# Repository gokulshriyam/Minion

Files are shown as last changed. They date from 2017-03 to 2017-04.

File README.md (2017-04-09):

1. PRODUCT :

Minion is for all electricity consumers across the world to help reduce their power costs at an affordable price point using "user friendly" products & analysis.

As there are many IOT Smart Energy Devices in the market that ensures energy efficiency and cost saving but it makes monthly electric bills doubling or tripling every month, with no increase in energy usage. 

We had carefully read solutions of all existing smart meters across the world and identified the perfect use case which ensures 100% energy efficiency and cost saving to the electricity consumers

Minion is a single device (size: 39x49 Millimeter - World's smallest pocket energy auditor) with Wi-Fi,LORA,3G/4G Connectivity which will fit inside the breaker panel (next to utility meter like addon) with single sensor clamp connection after the utility meter.

This Minion will perform appliance/device/tool/equipment wise real-time energy analytics. It will also perform Predictive analytics & maintenance of assets (Hospital, Industrial, Manufacturing/factories, Hospitality, Retail) which rescues the high cost assets from breakdown and also lowers the insurance costs. It schedules maintenance which will ensure and extend the life-time of assets beyond insurance time.

Our Minion is also Solar friendly/compatible. It has the ability to measure generation and consumption readings (acts as net meter) and performs real time & predictive analytics. 

All the analytics are done on the cloud and enable users to experience the results through our SaaS - Windows application, Android & IoS Apps.

Our Minion provides three steps for ensuring 100% energy efficiency and cost saving

1. Realtime analytics - Let's user know what is he/she spending for at appliance level at any sectors (Residential, Hospitality, Hospitals, Industrial and more)

2. Predictive analytics - Reduces surprises in energy bills and User's can easily predict the energy usage and bills and schedule accordingly. This would be very useful for sectors running high cost assets which will prevent from breakdown and increase the efficiency of the assets.

3. Operating System (OS) - The predictive analytics with data and sensors leads to Operating system which ensures 100% of efficiency & cost saving. Without the help of human interfering, Our OS will perform automation inside buildings.

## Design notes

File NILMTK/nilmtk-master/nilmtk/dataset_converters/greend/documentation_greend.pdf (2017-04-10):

# GREEND Parser and Metadata for NILMTK

Johannes Holzl ¨
The Dark Side of Force
johannes.hoelzl@gmail.com

Abstract—GREEND[MEE⁺14] is a dataset which has been developed and collected in Carinthia and parts of Italy. It contains eight buildings and a couple of months of power measurement.
NILM-Metadata[KK14] is project which was designed for being used with NILM-TK[BKP⁺14], the free and open source Non-Intrusive Load Monitoring Toolkit.
I. INTRODUCTION

The GREEND parser has been developed in the thought of converting this particular dataset into a general, easy-to-use and most of all, a comparable structure. As many other parsers for NILM-TK, it converts the dataset into a standardized format which is also known as NILMTK-DF. Using a hdf5 file instead of a punch of csv or similar files has advantages such as the increase of performance when importing the dataset to the program, overall size on disk, which is much smaller and the circumstance that is just a single file containing all data and metadata makes it much more comfortable to use than the previously described scenario.

II. USING THE PARSER

The GREEND parser is stored in a file which is called convert_greend.py as the function convert_greend. It takes to strings as parameters which both describe paths. The first parameter gives in the path to the directory in which the GREEND dataset is stored. The second one is the location in which the outputted hdf5 file should be saved to.
When using the parser, keep in mind that GREEND is using up quite some disk space because of its sample rate of one second and its long recording period.
A. Example on using the GREEND parser

This Example shows the Usage of the GREEND parser which converts the data stored at greend/path to a hdf5 file at path/to/greend.h5.

convert_greend(’greend/path’, ’path/to/greend.h5’)

Fig. 1. Example of Converting GREEND

B. Using the Dataset

The hdf5 file could now be used with NILM-TK as expected. With NILM-TK v0.2 there is a class called HDFDataStore which could be, and is usually used to import hdf5 files. To finally load the dataset in form in which it could be used, it is indispensable to create a DataSet object and call its function load() with the HDFDataStore as a parameter.

C. Technical Background

The GREEND converter is not much different than the REDD one. They differ in the fact, that every meter contained in REDD has its own file with data in it, while in GREEND, every day is stored in a separate file with multiple columns for the appliances.

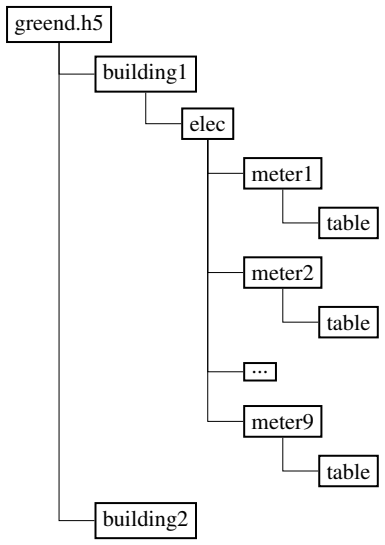
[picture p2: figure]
greend.h5; building1; elec; meter1; table; meter2; meter9; building2

Fig. 2. Structure of the Dataset

REFERENCES

[BKP⁺14] Nipun Batra, Jack Kelly, Oliver Parson, Haimonti Dutta, William Knottenbelt, Alex Rogers, Amarjeet Singh, and Mani Srivastava. Nilmtk: An open source toolkit for non-intrusive load monitoring. In Proceedings of the 5th International Conference on Future Energy Systems, e-Energy ’14, pages 265–276. ACM, 2014.
[KK14] | Jack Kelly and William Knottenbelt. | Metadata for Energy
Disaggregation. In The 2nd IEEE International Workshop on
Consumer Devices and Systems (CDS 2014), Vaster ¨ | as, Sweden, ˚
| July 2014.
[MEE⁺14] Andrea Monacchi, Dominik Egarter, Wilfried Elmenreich, Salvatore DAlessandro, and Andrea M. Tonello. GREEND: an energy consumption dataset of households in Italy and Austria. In Proceedings of the IEEE International Conference on Smart Grid Communications (SmartGridComm’14), November 2014.

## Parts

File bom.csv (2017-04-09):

Location | MPN | Quantity
C12, C11 | 06031A270JAT2A | 2
C14 | UWD1H221MCL1GS | 1
C15 | EEE-0GA101SR | 1
C5, C4, C13, C10 | 06035C333JAT2A | 4
C7, C3 | 0603YD334KAT2A | 2
C8, C1 | TAJA106K016RNJ | 2
C9, C6, C2, C17, C16 | GRM188R71H104KA93D | 5
D1 | MBRA140T3G | 1
D2 | B130LAW-7-F | 1
J1 | ST-PJ-312 | 1
J4 | 6.94E+11 | 1
PWR | LTST-C190KGKT | 1
Q1 | ABLS3-8.192MHZ-D4Y-T | 1
R10 | CR0603-FX-1003ELF | 1
R12 | 1-1614884-9 | 1
R5, R1 | ERJ-3EKF1000V | 2
R8, R7 | CRCW06032R40FKEAHP | 2
R9, R6, R3, R2, R13 | CRCW06031K00FKEA | 5
U1 | ATM90E26-YU-R | 1
U2 | TLV1117-50CDCYR | 1
J3, J2 | 110990037 | 2
R11 | RC0603JR-070RL | 1

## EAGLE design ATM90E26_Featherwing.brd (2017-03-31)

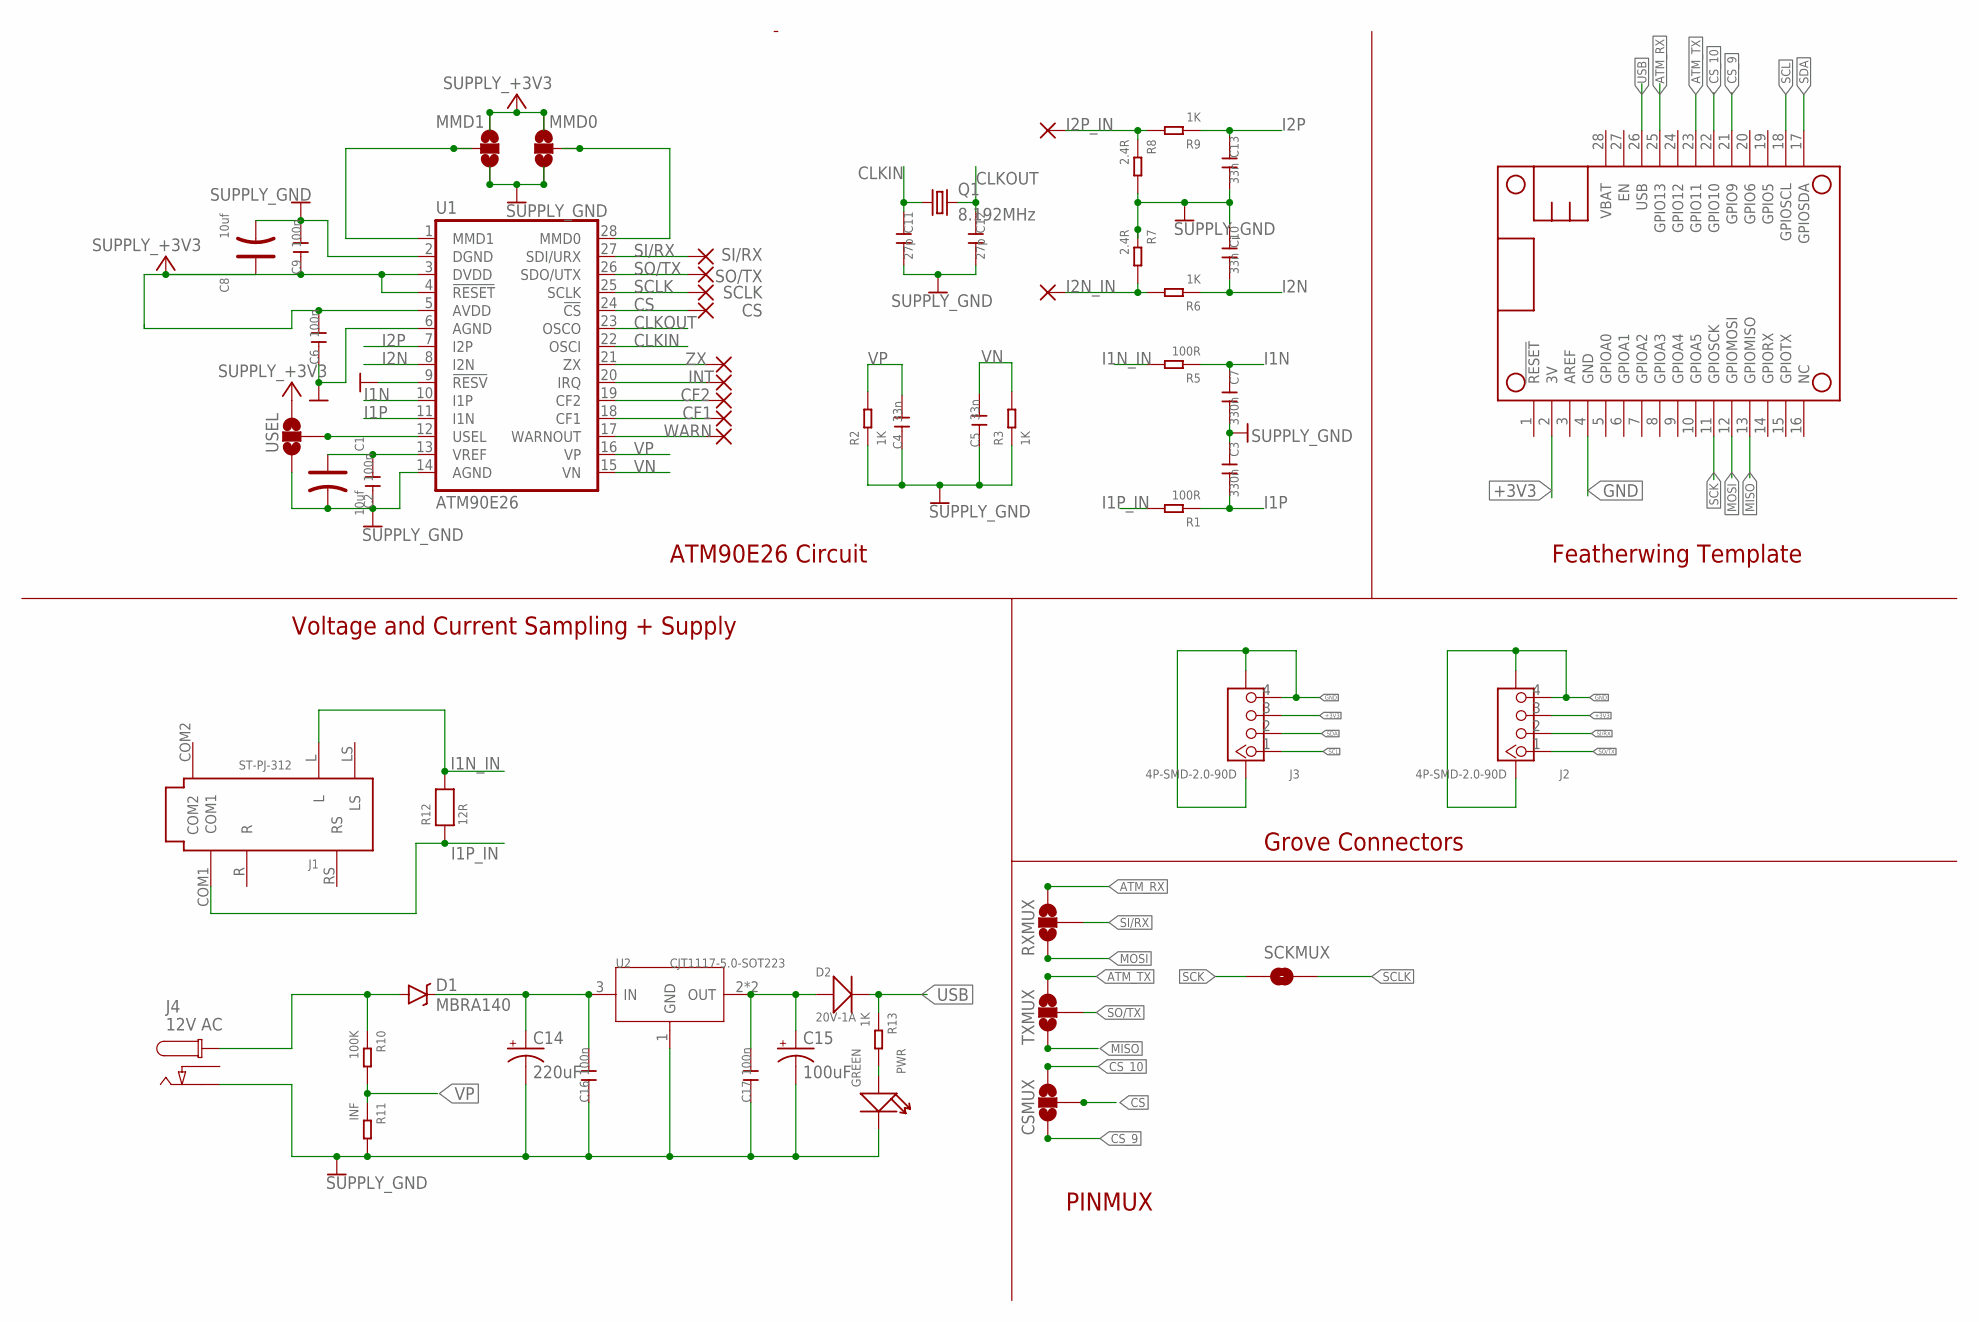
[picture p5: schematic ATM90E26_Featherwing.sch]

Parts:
C1, C8: 10uf; AVX-A
C2, C6, C9, C16, C17: 100n; C0603
C3, C7: 330n; C0603
C4, C5, C10, C13: 33n; C0603
C11, C12: 27p; C0603
C14: 220uF; 140CLH-1010
C15: 100uF; 153CLV-0605
CF1, CF2: WIREPADSMD1,27-254; SMD1,27-2,54
CS: WIREPADSMD1,27-254; SMD1,27-2,54
CSMUX: JUMPER-PAD-3-NOYES_SILK; PAD-JUMPER-3-NO_YES_SILK
D1: MBRA140; SMA-DIODE
D2: 20V-1A; SOD-123
I2N_IN, I2P_IN: WIREPADSMD1,27-254; SMD1,27-2,54
INT: WIREPADSMD1,27-254; SMD1,27-2,54
J1: ST-PJ-312; AUDIO6P-SMD-3.5-14.0X6.4X5.0MM
J2, J3: 4P-SMD-2.0-90D; HW4-SMD-2.0-90D
J4: 12V AC; DC_BARREL_JACK_SMD_2MM
MMD0, MMD1: JUMPER-PAD-3-NOFULL_BOX_SILK; PAD-JUMPER-3-NO_YES_SILK_FULL_BOX
MS1: FEATHERWING_NODIM; FEATHERWING_DIM
PWR: GREEN; LED-0603
Q1: 8.192MHz; HC49UP
R1, R5: 100R; R0603
R2, R3, R6, R9, R13: 1K; R0603
R7, R8: 2.4R; R0603
R10: 100K; R0603
R11: INF; R0603
R12: 12R; 0805
RXMUX: JUMPER-PAD-3-NOYES_SILK; PAD-JUMPER-3-NO_YES_SILK
SCKMUX: JUMPER-PAD-2-NOYES_SILK; PAD-JUMPER-2-NO_YES_SILK
SCLK: WIREPADSMD1,27-254; SMD1,27-2,54
SI/RX: WIREPADSMD1,27-254; SMD1,27-2,54
SO/TX: WIREPADSMD1,27-254; SMD1,27-2,54
TXMUX: JUMPER-PAD-3-NOYES_SILK; PAD-JUMPER-3-NO_YES_SILK
U1: ATM90E26; SSOP-28
U2: CJT1117-5.0-SOT223; SOT-223
USEL: JUMPER-PAD-3-NOFULL_BOX_SILK; PAD-JUMPER-3-NO_YES_SILK_FULL_BOX
WARN: WIREPADSMD1,27-254; SMD1,27-2,54
ZX: WIREPADSMD1,27-254; SMD1,27-2,54

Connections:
+3V3: C6.2, C8.+, C9.1, J2.3, J3.3, MMD0.3, MMD1.1, MS1.2 (3V), U1.3 (DVDD), U1.4 (!RESET), U1.5 (AVDD), USEL.3
ATM_RX: MS1.25 (GPIO13), RXMUX.3
ATM_TX: MS1.23 (GPIO11), TXMUX.3
CLKIN: C11.1, Q1.1, U1.22 (OSCI)
CLKOUT: C12.1, Q1.2, U1.23 (OSCO)
CS: CS.1, CSMUX.2, U1.24 (!CS)
CS_9: CSMUX.1, MS1.21 (GPIO9)
CS_10: CSMUX.3, MS1.22 (GPIO10)
GND: C1.-, C2.1, C3.1, C4.1, C5.1, C6.1, C7.2, C8.-, C9.2, C10.1, C11.2, C12.2, C13.2, C14.-, C15.-, C16.1, C17.1, J2.4, J2.SS1, J2.SS2, J3.4, J3.SS1, J3.SS2, J4.P2, MMD0.1, MMD1.3, MS1.4 (GND), PWR.-, R2.1, R3.1, R7.1, R8.2, R11.2, U1.2 (DGND), U1.6 (AGND), U1.9 (!RESV), U1.14 (AGND), U2.1 (GND), USEL.1
I1N: C7.1, R5.1, U1.10 (I1P)
I1N_IN: J1.L, R5.2, R12.2
I1P: C3.2, R1.1, U1.11 (I1N)
I1P_IN: J1.COM1, R1.2, R12.1
I2N: C10.2, R6.1, U1.8 (I2N)
I2N_IN: I2N_IN.1, R6.2, R7.2
I2P: C13.1, R9.1, U1.7 (I2P)
I2P_IN: I2P_IN.1, R8.1, R9.2
MISO: MS1.13 (GPIOMISO), TXMUX.1
MOSI: MS1.12 (GPIOMOSI), RXMUX.1
unnamed: MMD1.2, U1.1 (MMD1)
unnamed: MMD0.2, U1.28 (MMD0)
unnamed: D1.A, J4.P1@2 (P1), R10.1
unnamed: C14.+, C16.2, D1.C, U2.3 (IN)
unnamed: PWR.+, R13.2
unnamed: CF1.1, U1.18 (CF1)
unnamed: CF2.1, U1.19 (CF2)
unnamed: U1.12 (USEL), USEL.2
unnamed: U1.21 (ZX), ZX.1
unnamed: INT.1, U1.20 (IRQ)
unnamed: U1.17 (WARNOUT), WARN.1
SCK: MS1.11 (GPIOSCK), SCKMUX.1
SCL: J3.1, MS1.18 (GPIOSCL)
SCLK: SCKMUX.2, SCLK.1, U1.25 (SCLK)
SDA: J3.2, MS1.17 (GPIOSDA)
SI/RX: J2.2, RXMUX.2, SI/RX.1, U1.27 (SDI/URX)
SO/TX: J2.1, SO/TX.1, TXMUX.2, U1.26 (SDO/UTX)
USB: D2.-, MS1.26 (USB), R13.1
VN: C5.2, R3.2, U1.15 (VN)
VP: C4.2, R2.2, R10.2, R11.1, U1.16 (VP)
VREF: C1.+, C2.2, U1.13 (VREF)
V_OUT: C15.+, C17.2, D2.+, U2.2 (OUT), U2.TER (OUT)

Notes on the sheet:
ATM90E26 Circuit
Featherwing Template
Voltage and Current Sampling + Supply
Grove Connectors
PINMUX

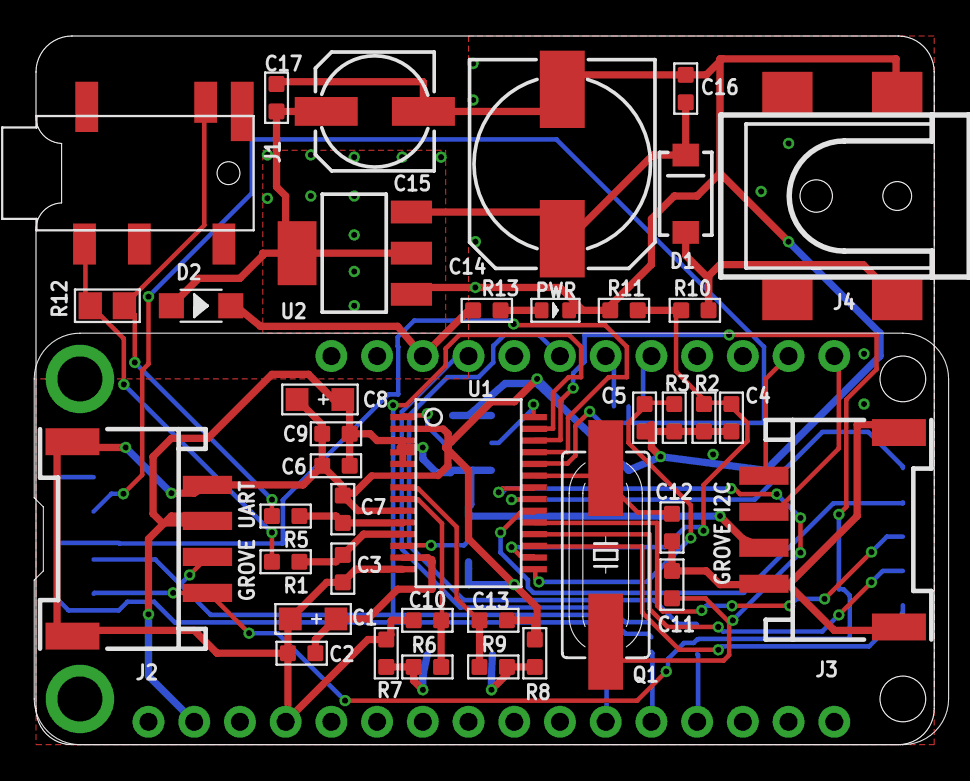
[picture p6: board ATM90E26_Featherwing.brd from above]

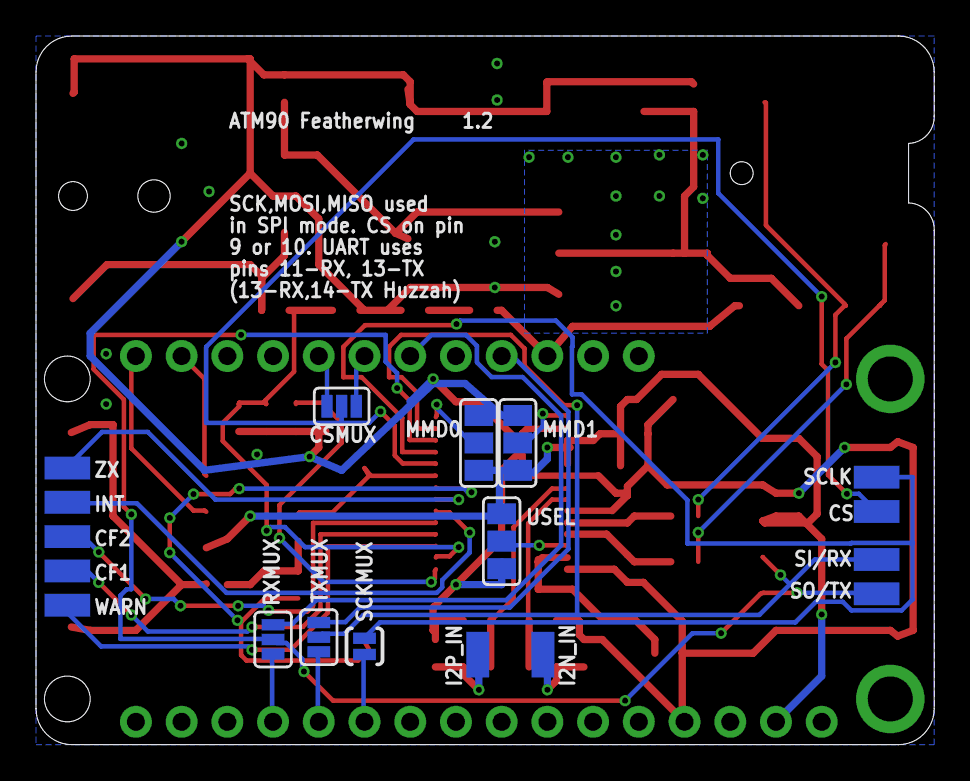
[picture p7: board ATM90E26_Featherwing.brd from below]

Board: 2 copper layers, 49.9 x 39.4 mm, 58 parts (18 on the bottom side), 41 nets.

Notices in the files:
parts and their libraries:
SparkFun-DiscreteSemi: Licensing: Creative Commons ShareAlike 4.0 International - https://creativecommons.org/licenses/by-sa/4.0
